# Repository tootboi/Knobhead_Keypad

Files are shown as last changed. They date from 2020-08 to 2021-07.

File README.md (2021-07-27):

# Knobhead Keypad
### Multi-functional custom Keypad

This project uses a Pro Micro with an ATmega32U4 on board. It allows the user to configure and use the rotary encoder, 9 mechanical switches and 3 rgb LEDs in many different ways, such as:
- Media keys (e.g. volume control, play/pause, ...)
- Macro keys (e.g. ctrl + Z, ctrl + shift + esc, ...)
- Mouse control (e.g. moving the cursor, middle click, ...)
- Keypad layer control
- Change LED colour and function

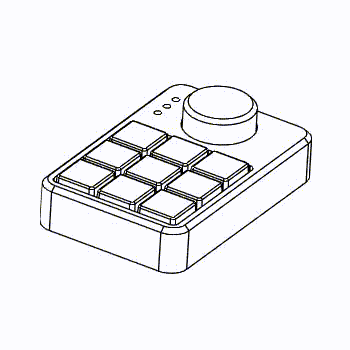
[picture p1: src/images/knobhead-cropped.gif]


## Components
- 1x Pro Micro
- 1x EC11 rotary encoder
- 9x mechanical switches
- 9x Kailh hotswap sockets
- 9x 1N4148 diodes
- 1x 28mm diameter aluminium knob OR a 3D printed knob
- 1x 3D printed case

## PCB
Autodesk Eagle files needed to view the pcb design is in Knobhead_Keypad/src/pcb/ directory.

### Schematic
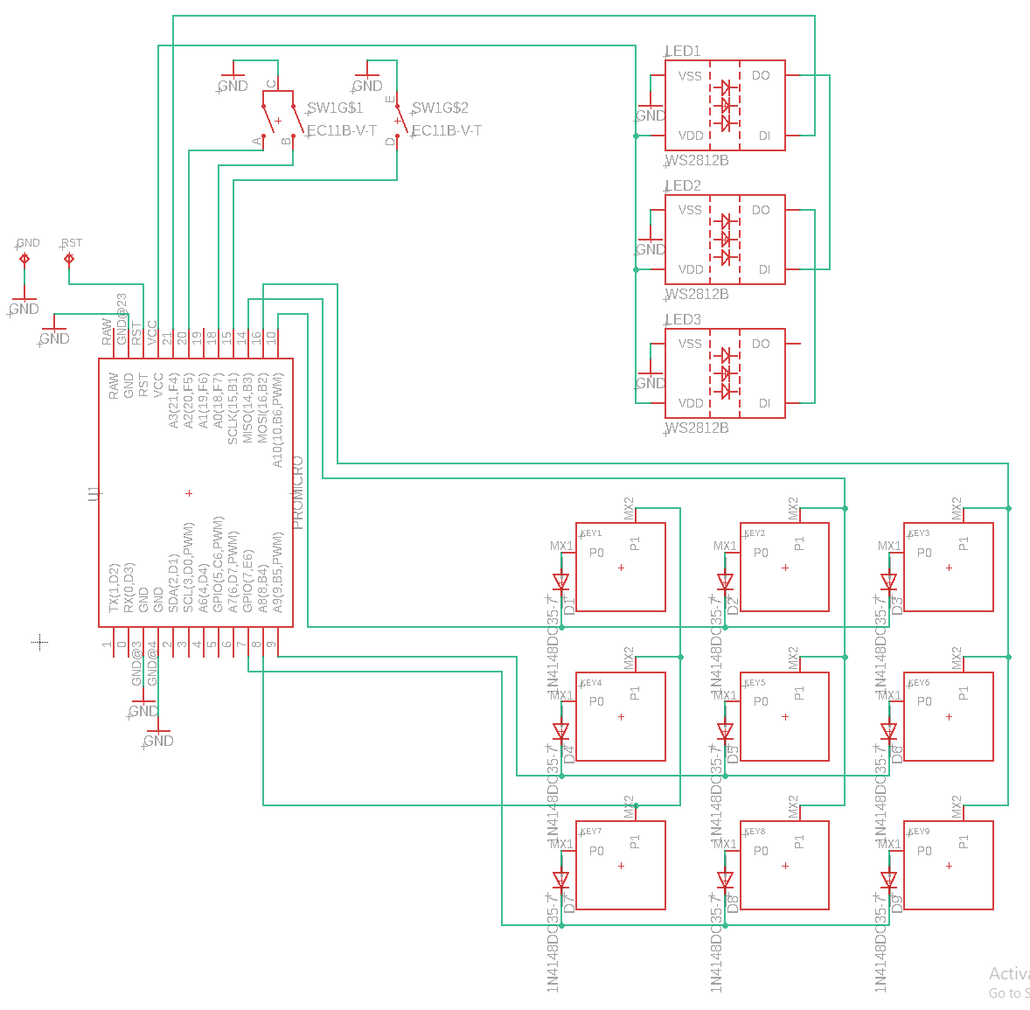
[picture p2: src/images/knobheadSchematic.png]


### Snapshot of pcb
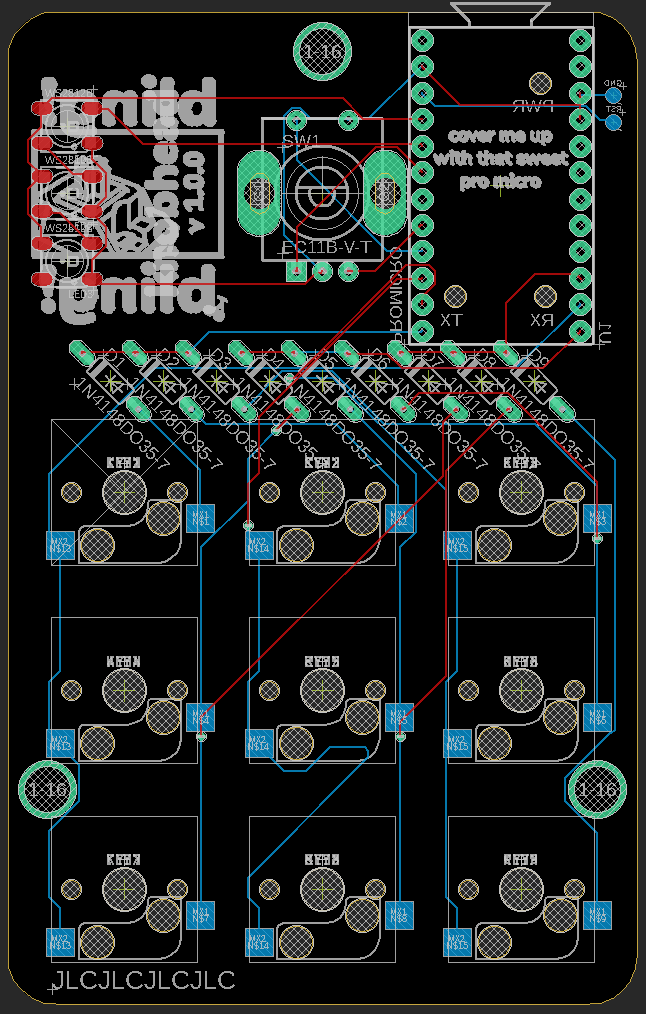
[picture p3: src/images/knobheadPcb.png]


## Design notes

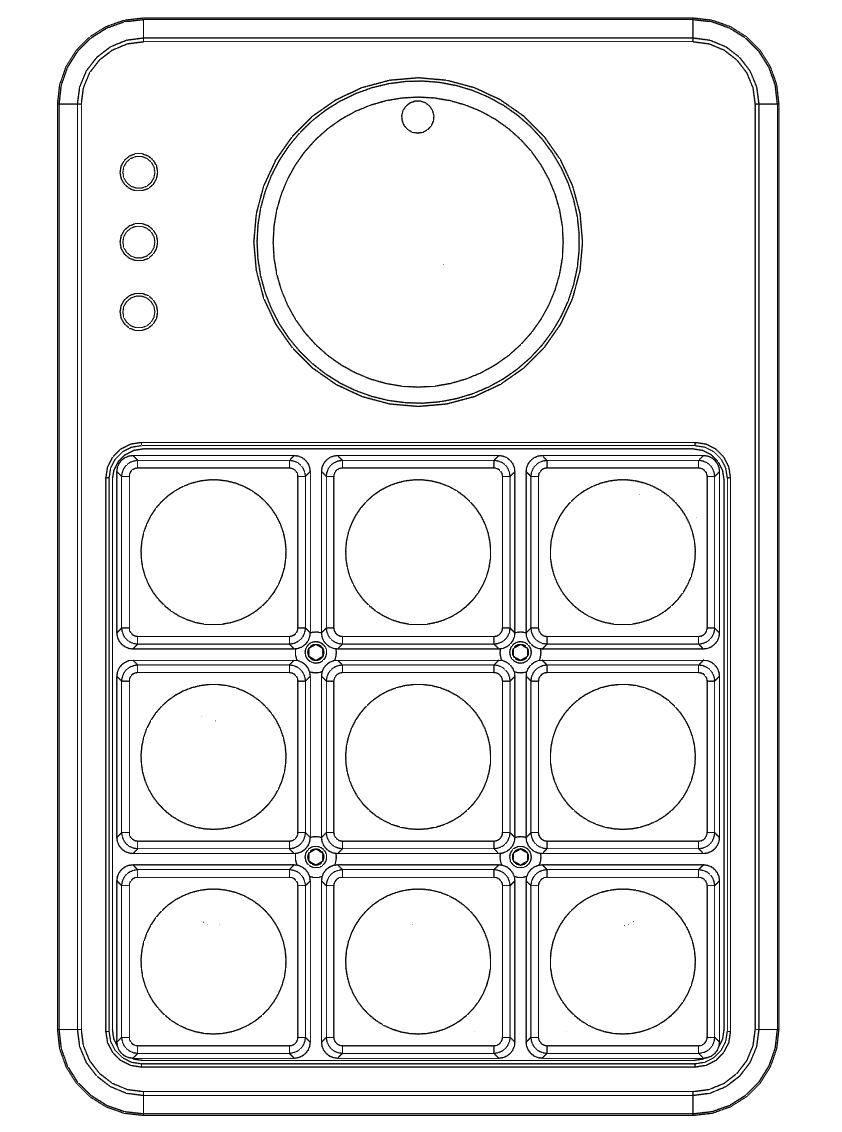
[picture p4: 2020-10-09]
src/images/front.png

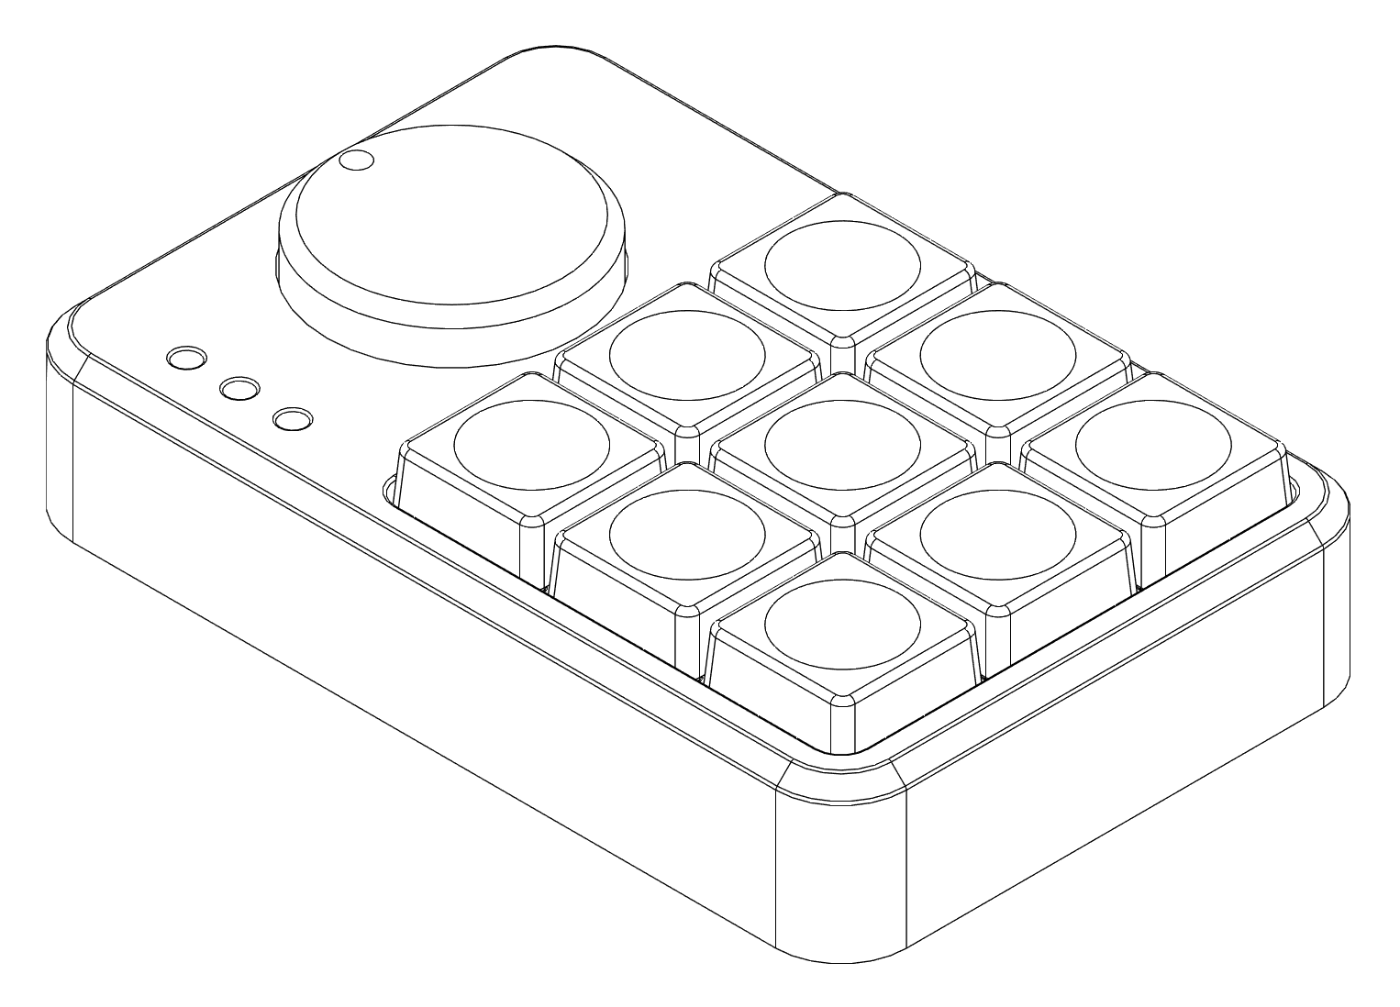
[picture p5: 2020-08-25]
src/images/isometricView.png

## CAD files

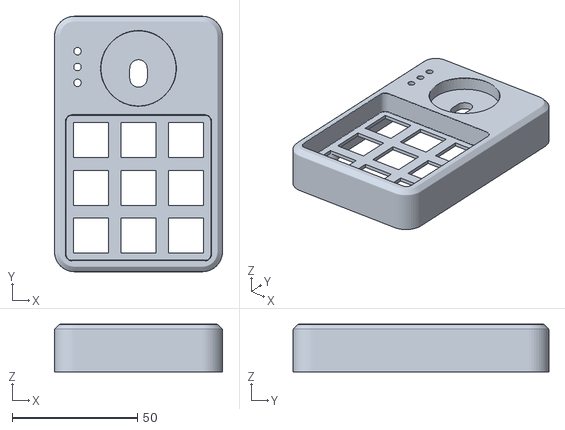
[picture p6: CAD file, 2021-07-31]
src/stl/knobheadCaseOpaque.stl
67.2 x 102.1 x 19.0

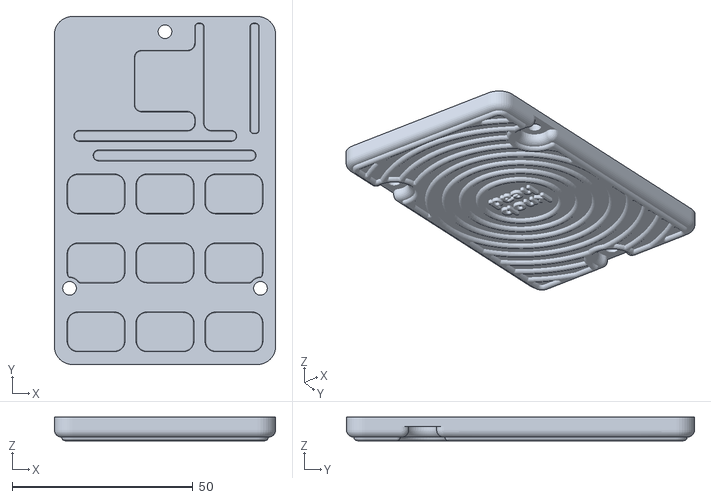
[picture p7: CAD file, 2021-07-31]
src/stl/knobheadBackplate.stl
61.2 x 96.1 x 6.50

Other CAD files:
src/stl/knobheadCaseTranslucent.stl

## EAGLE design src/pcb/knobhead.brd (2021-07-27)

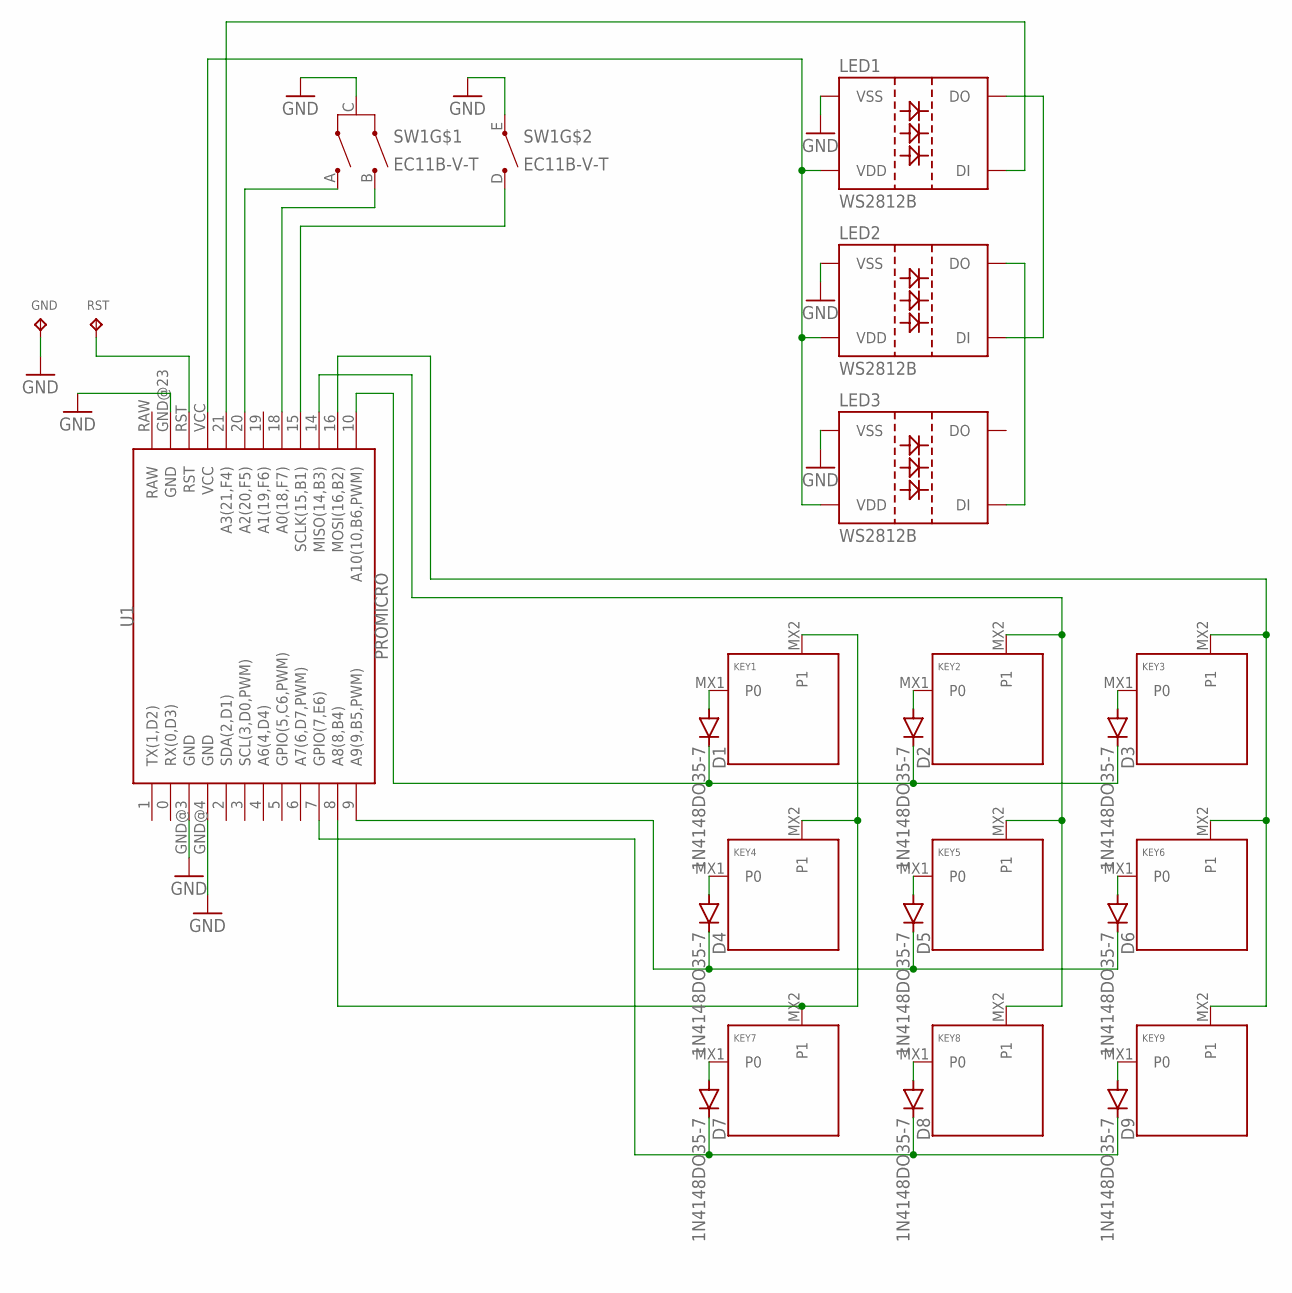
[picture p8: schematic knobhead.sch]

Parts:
D1, D2, D3, D4, D5, D6, D7, D8, D9: 1N4148DO35-7; DO35-7
GND: TPB1,27; B1,27
KEY1, KEY2, KEY3, KEY4, KEY5, KEY6, KEY7, KEY8, KEY9: KEYSWITCH-PLAIN-MXHSPCB-1U; MXHSPCB-1U
LED1, LED2, LED3: WS2812B
RST: TPB1,27; B1,27
SW1: EC11B-V-T; EC11B-V
U1: PROMICRO

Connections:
GND: GND.TP, LED1.3 (VSS), LED2.3 (VSS), LED3.3 (VSS), SW1.C, SW1.E, U1.GND@3 (GND), U1.GND@4 (GND), U1.GND@23 (GND)
unnamed: D1.A, KEY1.MX1 (P0)
unnamed: D2.A, KEY2.MX1 (P0)
unnamed: D3.A, KEY3.MX1 (P0)
unnamed: D4.A, KEY4.MX1 (P0)
unnamed: D5.A, KEY5.MX1 (P0)
unnamed: D6.A, KEY6.MX1 (P0)
unnamed: D7.A, KEY7.MX1 (P0)
unnamed: D8.A, KEY8.MX1 (P0)
unnamed: D9.A, KEY9.MX1 (P0)
unnamed: D1.C, D2.C, D3.C, U1.10 (A10(10,B6,PWM))
unnamed: D4.C, D5.C, D6.C, U1.9 (A9(9,B5,PWM))
unnamed: D7.C, D8.C, D9.C, U1.7 (GPIO(7,E6))
unnamed: KEY1.MX2 (P1), KEY4.MX2 (P1), KEY7.MX2 (P1), U1.8 (A8(8,B4))
unnamed: KEY2.MX2 (P1), KEY5.MX2 (P1), KEY8.MX2 (P1), U1.14 (MISO(14,B3))
unnamed: KEY3.MX2 (P1), KEY6.MX2 (P1), KEY9.MX2 (P1), U1.16 (MOSI(16,B2))
unnamed: LED1.1 (VDD), LED2.1 (VDD), LED3.1 (VDD), U1.VCC
unnamed: LED1.4 (DI), U1.21 (A3(21,F4))
unnamed: LED1.2 (DO), LED2.4 (DI)
unnamed: LED2.2 (DO), LED3.4 (DI)
unnamed: SW1.A, U1.20 (A2(20,F5))
unnamed: SW1.B, U1.18 (A0(18,F7))
unnamed: SW1.D, U1.15 (SCLK(15,B1))
unnamed: RST.TP, U1.RST

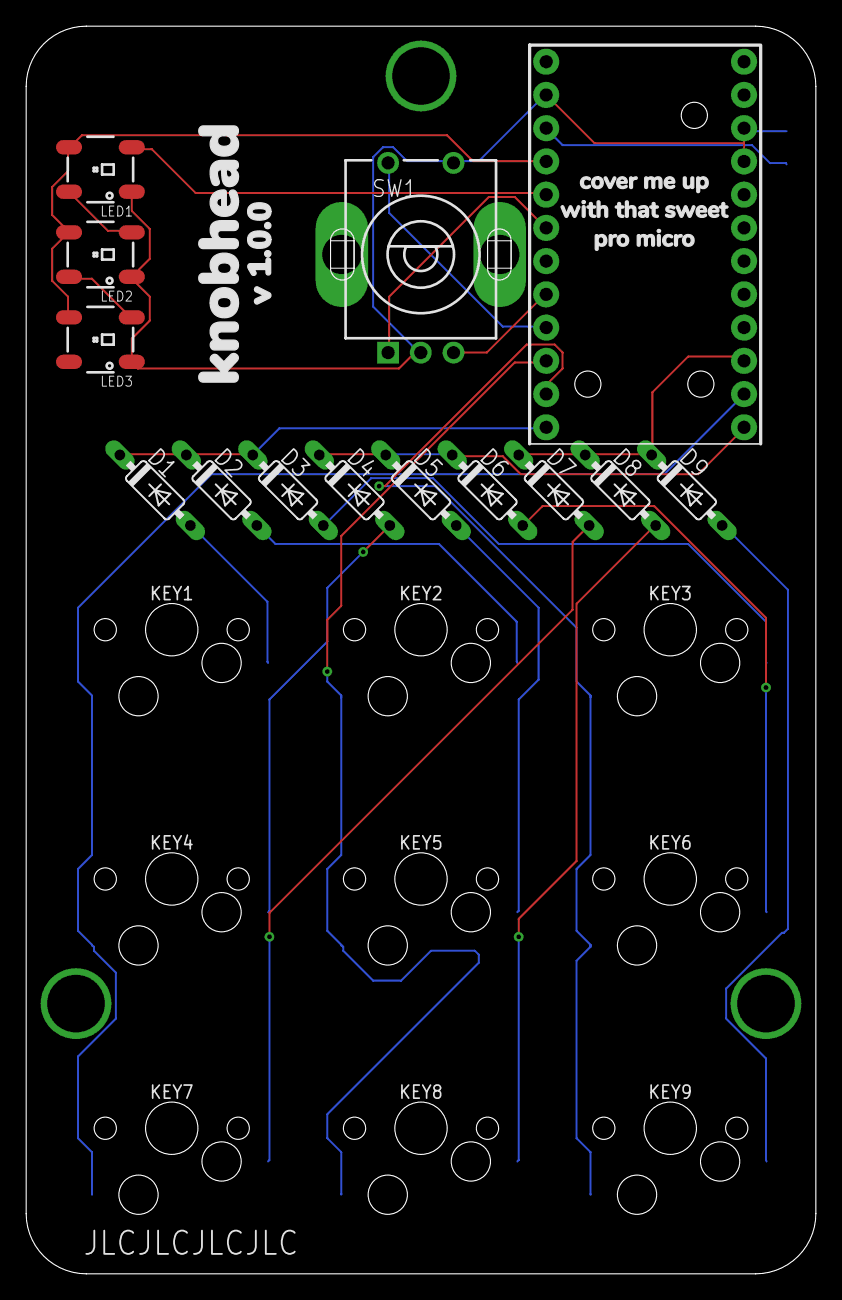
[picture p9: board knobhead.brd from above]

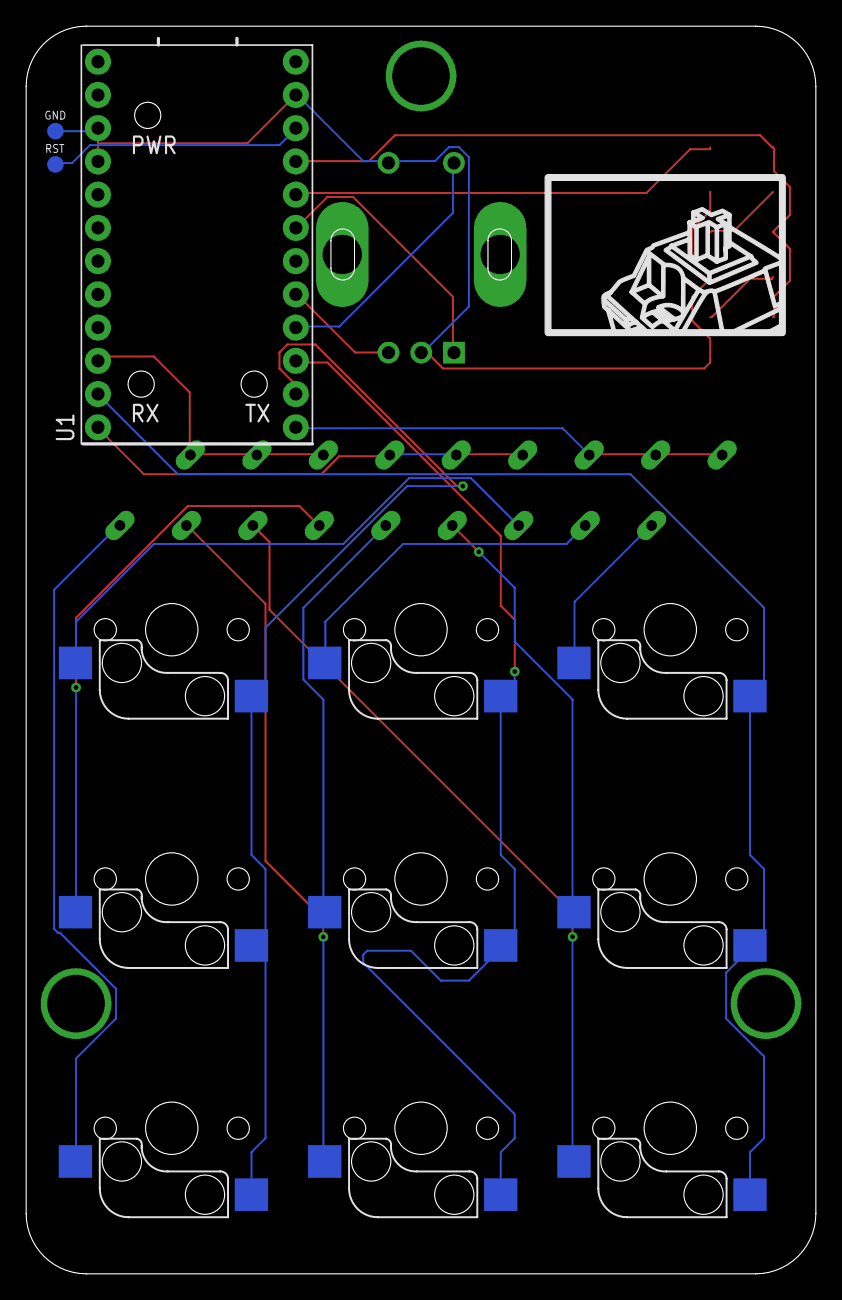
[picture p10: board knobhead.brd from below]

Board: 2 copper layers, 60.4 x 95.3 mm, 25 parts (12 on the bottom side), 24 nets.

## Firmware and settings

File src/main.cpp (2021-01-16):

#include <Arduino.h>
#include <HID-Project.h>
#include <Adafruit_NeoPixel.h>

//variables for LED timeout
const unsigned long timeout = 60000;   //timeout in millisecond. change this value to adjust timeout
unsigned long idleTime;
bool idleStart = false;
bool idle = false;
bool rainbow = false;
bool timeoutEnabled = true;

//variables for NeoPixel
#define ledStripPin A3
#define ledCount 3

Adafruit_NeoPixel strip(ledCount, ledStripPin, NEO_GRB + NEO_KHZ800);

//variables for keypad matrix
const int rowNum = 3;
const int colNum = 3;

byte rowPins[rowNum] = {10, 9, 7};
byte colPins[colNum] = {8, 14, 16};

int getKey();

//    btn matrix layout:
//    |----------------|
//    |[1]    [2]   [3]|
//    |[4]    [5]   [6]|
//    |[7]    [8]   [9]|
//    |----------------|

//variable for layers
int layer = 0;
bool subLayer = false;

void layerChange(byte sign);
void checkBit(byte layer, byte bit, byte led, uint32_t rgb);

//variables for rotary encoder
#define outputA A2
#define outputB A0
const int pulseDebounce = 0;
unsigned long lastPulse = 0;

uint8_t tableDecode();

#define encoderBtn 15

uint8_t getClick();

void setup() {
  Serial.begin(9600);

  //setup for NeoPixel
  strip.begin();
  strip.show();

  //setup for keypad matrix
  for(byte c=0; c<colNum; c++) {
    pinMode(colPins[c], INPUT_PULLUP);
  }

  //setup for rotarty encoder
  pinMode(outputA, INPUT_PULLUP);
  pinMode(outputB, INPUT_PULLUP);
  pinMode(encoderBtn, INPUT_PULLUP);

  Consumer.begin(); //For writing media keys.
  Keyboard.begin(); //For writing normal keys.
  BootKeyboard.begin(); //For keyboard leds.
  Mouse.begin();
}

void loop() {
  //for timeout
  bool noInput = true;

  //code for layer leds
  if(!idle) strip.setBrightness(12);
  switch(layer) {
    //layer 0
    case 0:
      if(subLayer) {
        //sublayer
        strip.clear();
        uint32_t color0 = strip.Color(255, 255, 0);
        uint32_t color1 = strip.Color(0, 0, 255);
        uint32_t color2 = strip.Color(0, 0, 255);
        checkBit(layer, 1, 1, color1);
        checkBit(layer, 0, 2, color2);
        //code for led indicate
        if(BootKeyboard.getLeds() & LED_CAPS_LOCK) {  //for changing what led0 indicates
          strip.setPixelColor(0, color0); //for changing led0 color
        }
      } else {
        //main
        strip.clear();
        uint32_t color0 = strip.Color(255, 255, 0);
        uint32_t color1 = strip.Color(0, 255, 0);
        uint32_t color2 = strip.Color(0, 255, 0);
        checkBit(layer, 1, 1, color1);
        checkBit(layer, 0, 2, color2);
        //code for led indicate
        if(BootKeyboard.getLeds() & LED_CAPS_LOCK) {  //for changing what led0 indicates
          strip.setPixelColor(0, color0); //for changing led0 color
        }
      }
      break;
    //layer 1
    case 1:
      if(subLayer){
        strip.clear();
        uint32_t color0 = strip.Color(255, 255, 0);
        uint32_t color1 = strip.Color(0, 0, 255);
        uint32_t color2 = strip.Color(0, 0, 255);
        checkBit(layer, 1, 1, color1);
        checkBit(layer, 0, 2, color2);
        //code for led indicate
        if(BootKeyboard.getLeds() & LED_CAPS_LOCK) {  //for changing what led0 indicates
          strip.setPixelColor(0, color0); //for changing led0 color
        }
      } else {
        strip.clear();
        uint32_t color0 = strip.Color(255, 255, 0);
        uint32_t color1 = strip.Color(0, 255, 0);
        uint32_t color2 = strip.Color(0, 255, 0);
        checkBit(layer, 1, 1, color1);
        checkBit(layer, 0, 2, color2);
        //code for led indicate
        if(BootKeyboard.getLeds() & LED_CAPS_LOCK) {  //for changing what led0 indicates
          strip.setPixelColor(0, color0); //for changing led0 color
        }
      }
      break;
    //layer 2
    case 2:
      if(subLayer){
        strip.clear();
        uint32_t color0 = strip.Color(0, 113, 128);
        uint32_t color1 = strip.Color(0, 0, 255);
        uint32_t color2 = strip.Color(0, 0, 255);
        checkBit(layer, 1, 1, color1);
        checkBit(layer, 0, 2, color2);
        //code for led indicate
        if(BootKeyboard.getLeds() & LED_NUM_LOCK) {  //for changing what led0 indicates
          strip.setPixelColor(0, color0); //for changing led0 color
        }
      } else {
        strip.clear();
        uint32_t color0 = strip.Color(255, 255, 0);
        uint32_t color1 = strip.Color(0, 255, 0);
        uint32_t color2 = strip.Color(0, 255, 0);
        checkBit(layer, 1, 1, color1);
        checkBit(layer, 0, 2, color2);
        //code for led indicate
        if(BootKeyboard.getLeds() & LED_CAPS_LOCK) {  //for changing what led0 indicates
          strip.setPixelColor(0, color0); //for changing led0 color
        }
      }
      break;
    //layer 3
    case 3:
      if(subLayer){
        strip.clear();
        uint32_t color0 = strip.Color(255, 255, 0);
        uint32_t color1 = strip.Color(0, 0, 255);
        uint32_t color2 = strip.Color(0, 0, 255);
        checkBit(layer, 1, 1, color1);
        checkBit(layer, 0, 2, color2);
        //code for led indicate
        if(BootKeyboard.getLeds() & LED_CAPS_LOCK) {  //for changing what led0 indicates
          strip.setPixelColor(0, color0); //for changing led0 color
        }
      } else {
        strip.clear();
        uint32_t color0 = strip.Color(255, 255, 0);
        uint32_t color1 = strip.Color(0, 255, 0);
        uint32_t color2 = strip.Color(0, 255, 0);
        checkBit(layer, 1, 1, color1);
        checkBit(layer, 0, 2, color2);
        //code for led indicate
        if(BootKeyboard.getLeds() & LED_CAPS_LOCK) {  //for changing what led0 indicates
          strip.setPixelColor(0, color0); //for changing led0 color
        }
      }
      break;
      
    default:
      break;
  }
  
  uint8_t clickType = getClick();
  uint8_t direction = tableDecode();
  uint8_t key = getKey();
  //for timeout
  if(key || direction || clickType) noInput = false, idleStart = true, idle = false;

  switch (layer) {
    //layer 0
    case 0:
      //code for keypad
      if(key){
        Serial.print("key: ");
        Serial.println(key);
        switch (key) {
          case 1:
            if(subLayer) {
              //sublayer
              //code    //change this line to modify functions.
            } else {
              Keyboard.print("layer 0 ");    //change this line to modify functions.
            }
            break;
          case 2:
            if(subLayer) {
              //sublayer
              //code    //change this line to modify functions.
            } else {
              Consumer.write(CONSUMER_CALCULATOR);    //change this line to modify functions.
            }
            break;
          case 3:
            if(subLayer) {
              //sublayer
              //code    //change this line to modify functions.
            } else {
              Keyboard.press(KEY_PAGE_UP);    //change this line to modify functions.
            }
            break;
          case 4:
            if(subLayer) {
              //sublayer
              //code    //change this line to modify functions.
            } else {
              Keyboard.press(KEY_LEFT_CTRL);    //change this line to modify functions.
              Keyboard.print("z");    //change this line to modify functions.
            }
            break;
          case 5:
            if(subLayer) {
              //sublayer
              //code    //change this line to modify functions.
            } else {
              Keyboard.press(KEY_LEFT_CTRL);    //change this line to modify functions.
              Keyboard.press('y');    //change this line to modify functions.
            }
            break;
          case 6:
            if(subLayer) {
              //sublayer
              //code    //change this line to modify functions.
            } else {
              Keyboard.press(KEY_PAGE_DOWN);    //change this line to modify functions.
            }
            break;
          case 7:
            if(subLayer) {
              //sublayer
              //code    //change this line to modify functions.
            } else {
              Keyboard.press(KEY_LEFT_CTRL);    //change this line to modify functions.
              Keyboard.press('x');    //change this line to modify functions.
            }
            break;
          case 8:
            if(subLayer) {
              //sublayer
              //code    //change this line to modify functions.
            } else {
              Keyboard.press(KEY_LEFT_CTRL);    //change this line to modify functions.
              Keyboard.press('c');    //change this line to modify functions.
            }
            break;
          case 9:
            if(subLayer) {
              //sublayer
              //code    //change this line to modify functions.
            } else {
              Keyboard.press(KEY_LEFT_CTRL);    //change this line to modify functions.
              Keyboard.press('v');    //change this line to modify functions.
            }
            break;

          default:
            break;
        }
        Keyboard.releaseAll();    //release all keys
      }
      
      //code for rotary encoder
      if(clickType) {
        switch(clickType) {
          case 1: //single
            if(subLayer) {
              //sublayer
              subLayer = !subLayer;
            } else {
              Consumer.write(MEDIA_VOLUME_MUTE);
            }
            break;
          case 2: //double
            if(subLayer) {
              //sublayer
              layerChange(0);
            } else {
              layerChange(0);
            }
            break;
          case 3: //long
            if(subLayer) {
              //sublayer
              layerChange(1);
            } else {
              layerChange(1);
            }
            break;

          default:
            break;
        }
        clickType = 0;
      }
      if(direction) {
        switch (direction) {
          case 1:     //clockwise
            if(subLayer) {
              Consumer.write(MEDIA_VOLUME_UP);
            } else {
              Consumer.write(MEDIA_VOLUME_UP);
            }
            break;
          case 2:     //anti-clockwise
            if(subLayer) {
              Consumer.write(MEDIA_VOLUME_DOWN);
            } else {
              Consumer.write(MEDIA_VOLUME_DOWN);
            }
            break;

          default:
            break;
        }
      }
      Keyboard.releaseAll();    //release all keys
      break;
      
    //layer 1
    case 1:
      //code for keypad
      if(key){
        Serial.print("key: ");
        Serial.println(key);
        switch (key) {
          case 1:
            if(subLayer) {
              //sublayer
              //code    //change this line to modify functions.
            } else {
              Keyboard.print("layer 1 ");    //change this line to modify functions.
            }
            break;
          case 2:
            if(subLayer) {
              //sublayer
              //code    //change this line to modify functions.
            } else {
              Keyboard.press(KEY_LEFT_SHIFT);    //change this line to modify functions.
              Keyboard.press(KEY_LEFT_ALT);    //change this line to modify functions.
              Keyboard.press(KEY_LEFT_CTRL);    //change this line to modify functions.
              Keyboard.press(KEY_F1);    //change this line to modify functions.
            }
            break;
          case 3:
            if(subLayer) {
              //sublayer
              //code    //change this line to modify functions.
            } else {
              rainbow = !rainbow;    //change this line to modify functions.
            }
            break;
          case 4:
            if(subLayer) {
              //sublayer
              //code    //change this line to modify functions.
            } else {
              //code    //change this line to modify functions.
            }
            break;
          case 5:
            if(subLayer) {
              //sublayer
              //code    //change this line to modify functions.
            } else {
              //code    //change this line to modify functions.
            }
            break;
          case 6:
            if(subLayer) {
              //sublayer
              //code    //change this line to modify functions.
            } else {
              //code    //change this line to modify functions.
            }
            break;
          case 7:
            if(subLayer) {
              //sublayer
              //code    //change this line to modify functions.
            } else {
              //code    //change this line to modify functions.
            }
            break;
          case 8:
            if(subLayer) {
              //sublayer
              //code    //change this line to modify functions.
            } else {
              //code    //change this line to modify functions.
            }
            break;
          case 9:
            if(subLayer) {
              //sublayer
              //code    //change this line to modify functions.
            } else {
              //code    //change this line to modify functions.
            }
            break;

          default:
            break;
        }
        Keyboard.releaseAll();    //release all keys
      }
      
      //code for rotary encoder
      if(clickType) {
        switch(clickType) {
          case 1: //single
            if(subLayer) {
              subLayer = !subLayer;
            } else {
              Consumer.write(MEDIA_VOLUME_MUTE);
            }
            break;
          case 2: //double
            if(subLayer) {
              layerChange(0);
            } else {
              layerChange(0);
            }
            break;
          case 3: //long
            if(subLayer) {
              layerChange(1);
            } else {
              layerChange(1);
            }
            break;

          default:
            break;
        }
        clickType = 0;
      }
      if(direction) {
        switch (direction) {
          case 1:     //clockwise
            if(subLayer) {
              Consumer.write(MEDIA_VOLUME_UP);
            } else {
              Consumer.write(MEDIA_VOLUME_UP);
            }
            break;
          case 2:     //anti-clockwise
            if(subLayer) {
              Consumer.write(MEDIA_VOLUME_DOWN);
            } else {
              Consumer.write(MEDIA_VOLUME_DOWN);
            }              
            break;

          default:
            break;
        }
      }
      Keyboard.releaseAll();  
      break;

    //layer 2
    case 2:
      //code for keypad
      if(key){
        Serial.print("key: ");
        Serial.println(key);
        switch (key) {
          case 1:
            if(subLayer) {
              //sublayer
              Keyboard.press(KEY_NUM_LOCK);    //change this line to modify functions.
            } else {
              Keyboard.press(KEYPAD_1);    //change this line to modify functions.
            }
            break;
          case 2:
            if(subLayer) {
              //sublayer
              //code    //change this line to modify functions.
            } else {
              Keyboard.press(KEYPAD_2);    //change this line to modify functions.
            }
            break;
          case 3:
            if(subLayer) {
              //sublayer
              //code    //change this line to modify functions.
            } else {
              Keyboard.press(KEYPAD_3);    //change this line to modify functions.
            }
            break;
          case 4:
            if(subLayer) {
              //sublayer
              //code    //change this line to modify functions.
            } else {
              Keyboard.press(KEYPAD_4);    //change this line to modify functions.
            }
            break;
          case 5:
            if(subLayer) {
              //sublayer
              //code    //change this line to modify functions.
            } else {
              Keyboard.press(KEYPAD_5);    //change this line to modify functions.
            }
            break;
          case 6:
            if(subLayer) {
              //sublayer
              //code    //change this line to modify functions.
            } else {
              Keyboard.press(KEYPAD_6);    //change this line to modify functions.
            }
            break;
          case 7:
            if(subLayer) {
              //sublayer
              Keyboard.press(KEYPAD_0);    //change this line to modify functions.
            } else {
              Keyboard.press(KEYPAD_7);    //change this line to modify functions.
            }
            break;
          case 8:
            if(subLayer) {
              //sublayer
              //code    //change this line to modify functions.
            } else {
              Keyboard.press(KEYPAD_8);    //change this line to modify functions.
            }
            break;
          case 9:
            if(subLayer) {
              //sublayer
              //code    //change this line to modify functions.
            } else {
              Keyboard.press(KEYPAD_9);    //change this line to modify functions.
            }
            break;

          default:
            break;
        }
        Keyboard.releaseAll();    //release all keys
      }
      
      //code for rotary encoder
      if(clickType) {
        switch(clickType) {
          case 1: //single
            if(subLayer) {
              subLayer = !subLayer;
            } else {
              subLayer = !subLayer;
            }              
            break;
          case 2: //double
            if(subLayer) {
              layerChange(0);
            } else {
              layerChange(0);
            }              
            break;
          case 3: //long
            if(subLayer) {
              layerChange(1);
            } else {
              layerChange(1);
            }              
            break;

          default:
            break;
        }
        clickType = 0;
      }
      if(direction) {
        switch (direction) {
          case 1:     //clockwise
            if(subLayer) {
              Keyboard.press(KEY_LEFT_CTRL);    //change this line to modify functions.
              Keyboard.press('+');    //change this line to modify functions.
            } else {
              Consumer.write(MEDIA_VOLUME_UP);
            }
            break;
          case 2:     //anti-clockwise
            if(subLayer) {
              Keyboard.press(KEY_LEFT_CTRL);    //change this line to modify functions.
              Keyboard.press('-');    //change this line to modify functions.
            } else {
              Consumer.write(MEDIA_VOLUME_DOWN);
            }
            break;

          default:
            break;
        }
      }
      Keyboard.releaseAll(); 
      break;

    //layer 3
    case 3:
      //code for keypad
      if(key){
        Serial.print("key: ");
        Serial.println(key);
        switch (key) {
          case 1:
            if(subLayer) {
              //sublayer
              //code    //change this line to modify functions.
            } else {
              Keyboard.print("1");    //change this line to modify functions.
            }
            break;
          case 2:
            if(subLayer) {
              //sublayer
              //code    //change this line to modify functions.
            } else {
              Keyboard.print("2");    //change this line to modify functions.
            }
            break;
          case 3:
            if(subLayer) {
              //sublayer
              //code    //change this line to modify functions.
            } else {
              Keyboard.print("3");   //change this line to modify functions.
            }
            break;
          case 4:
            if(subLayer) {
              //sublayer
              //code    //change this line to modify functions.
            } else {
              Keyboard.print("4");    //change this line to modify functions.
            }
            break;
          case 5:
            if(subLayer) {
              //sublayer
              //code    //change this line to modify functions.
            } else {
              Keyboard.print("5");    //change this line to modify functions.
            }
            break;
          case 6:
            if(subLayer) {
              //sublayer
              //code    //change this line to modify functions.
            } else {
              Keyboard.print("6");    //change this line to modify functions.
            }
            break;
          case 7:
            if(subLayer) {
              //sublayer
              //code    //change this line to modify functions.
            } else {
              Keyboard.print("7");    //change this line to modify functions.
            }
            break;
          case 8:
            if(subLayer) {
              //sublayer
              //code    //change this line to modify functions.
            } else {
              Keyboard.print("8");    //change this line to modify functions.
            }
            break;
          case 9:
            if(subLayer) {
              //sublayer
              //code    //change this line to modify functions.
            } else {
              Keyboard.print("9");    //change this line to modify functions.
            }
            break;
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

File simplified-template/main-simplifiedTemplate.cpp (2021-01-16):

#include <Arduino.h>
#include <HID-Project.h>
#include <Adafruit_NeoPixel.h>

#define ledStripPin A3
#define ledCount 3
#define outputA A2
#define outputB A0
#define encoderBtn 15

const unsigned long timeout = 60000;
unsigned long idleTime;
bool idleStart = false;
bool idle = false;
bool rainbow = false;
bool timeoutEnabled = false;
const int rowNum = 3;
const int colNum = 3;
byte rowPins[rowNum] = {10, 9, 7};
byte colPins[colNum] = {8, 14, 16};
int layer = 0;
bool subLayer = false;
const int pulseDebounce = 0;
unsigned long lastPulse = 0;

Adafruit_NeoPixel strip(ledCount, ledStripPin, NEO_GRB + NEO_KHZ800);

int getKey();
void layerChange(byte sign);
void checkBit(byte layer, byte bit, byte led, uint32_t rgb);
uint8_t tableDecode();
uint8_t getClick();

void setup() {
  Serial.begin(9600);
  strip.begin();
  strip.show();
  for(byte c=0; c<colNum; c++) {
    pinMode(colPins[c], INPUT_PULLUP);
  }
  pinMode(outputA, INPUT_PULLUP);
  pinMode(outputB, INPUT_PULLUP);
  pinMode(encoderBtn, INPUT_PULLUP);
  Consumer.begin();
  Keyboard.begin();
  BootKeyboard.begin();
  Mouse.begin();
}

void loop() {
  bool noInput = true;
  if(!idle) strip.setBrightness(12);

  switch(layer) {
    //layer 0
    case 0:
      if(subLayer) {
        //sublayer 0
        strip.clear();
      } else {
        //mainlayer 0
        strip.clear();
      }
      break;
    //layer 1
    case 1:
      if(subLayer){
        //sublayer 1
        strip.clear();
      } else {
        //mainlayer 1
        strip.clear();
      }
      break;
    //layer 2
    case 2:
      if(subLayer){
        //sublayer 2
        strip.clear();
      } else {
        //mainlayer 2
        strip.clear();
      }
      break;
    //layer 3
    case 3:
      if(subLayer){
        //sublayer 3
        strip.clear();
      } else {
        //mainlayer 3
        strip.clear();
      }
      break;
      
    default:
      break;
  }
  
  uint8_t clickType = getClick();
  uint8_t direction = tableDecode();
  uint8_t key = getKey();
  if(key || direction || clickType) noInput = false, idleStart = true, idle = false;

  switch (layer) {
    //layer 0
    case 0:
      if(key){
        switch (key) {
          case 1:
            if(subLayer) {
              //sublayer 0 key 1
            } else {
              //mainlayer 0 key 1
            }
            break;
          case 2:
            if(subLayer) {
              //sublayer 0 key 2
            } else {
              //mainlayer 0 key 2
            }
            break;
          case 3:
            if(subLayer) {
              //sublayer 0 key 3
            } else {
              //mainlayer 0 key 3
            }
            break;
          case 4:
            if(subLayer) {
              //sublayer 0 key 4
            } else {
              //mainlayer 0 key 4
            }
            break;
          case 5:
            if(subLayer) {
              //sublayer 0 key 5
            } else {
              //mainlayer 0 key 5
            }
            break;
          case 6:
            if(subLayer) {
              //sublayer 0 key 6
            } else {
              //mainlayer 0 key 6
            }
            break;
          case 7:
            if(subLayer) {
              //sublayer 0 key 7
            } else {
              //mainlayer 0 key 7
            }
            break;
          case 8:
            if(subLayer) {
              //sublayer 0 key 8
            } else {
              //mainlayer 0 key 8
            }
            break;
          case 9:
            if(subLayer) {
              //sublayer 0 key 9
            } else {
              //mainlayer 0 key 9
            }
            break;

          default:
            break;
        }
        Keyboard.releaseAll();
      }
      
      if(clickType) {
        switch(clickType) {
          case 1: //single
            if(subLayer) {
              //sublayer 0 single
            } else {
              //mainlayer 0 single
            }
            break;
          case 2: //double
            if(subLayer) {
              //sublayer 0 double
            } else {
              //mainlayer 0 double
            }
            break;
          case 3: //long
            if(subLayer) {
              //sublayer 0 long
            } else {
              //mainlayer 0 long
            }
            break;

          default:
            break;
        }
        clickType = 0;
      }
      if(direction) {
        switch (direction) {
          case 1:     //clockwise
            if(subLayer) {
              //sublayer 0 cw
            } else {
              //mainlayer 0 cw
            }
            break;
          case 2:     //anti-clockwise
            if(subLayer) {
              //sublayer 0 ccw
            } else {
              //mainlayer 0 ccw
            }
            break;

          default:
            break;
        }
      }
      Keyboard.releaseAll();
      break;
      
    //layer 1
    case 1:
      if(key){
        switch (key) {
          case 1:
            if(subLayer) {
              //sublayer 1 key 1
            } else {
              //mainlayer 1 key 1
            }
            break;
          case 2:
            if(subLayer) {
              //sublayer 1 key 2
            } else {
              //mainlayer 1 key 2
            }
            break;
          case 3:
            if(subLayer) {
              //sublayer 1 key 3
            } else {
              //mainlayer 1 key 3
            }
            break;
          case 4:
            if(subLayer) {
              //sublayer 1 key 4
            } else {
              //mainlayer 1 key 4
            }
            break;
          case 5:
            if(subLayer) {
              //sublayer 1 key 5
            } else {
              //mainlayer 1 key 5
            }
            break;
          case 6:
            if(subLayer) {
              //sublayer 1 key 6
            } else {
              //mainlayer 1 key 6
            }
            break;
          case 7:
            if(subLayer) {
              //sublayer 1 key 7
            } else {
              //mainlayer 1 key 7
            }
            break;
          case 8:
            if(subLayer) {
              //sublayer 1 key 8
            } else {
              //mainlayer 1 key 8
            }
            break;
          case 9:
            if(subLayer) {
              //sublayer 1 key 9
            } else {
              //mainlayer 1 key 9
            }
            break;
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

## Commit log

2020-08-25 capsLock LED implemented
2020-08-26 double clicking with encoder implemented
2020-08-28 fixed bug where encoder button presses will somtimes have ghost presses
    [main.cpp]
2020-08-30 implemented layers for the rotary encoder
2020-09-11 implemented functionality to hold and rotate rotary encoder
2020-09-26 now uses an led strip instead of individual leds
2020-09-28 reduced pulseDebounce for more responsive rotary encoder. And minor code refactoring
2020-09-28 encoder button now has layers
2020-10-23 edited some variables so it works with pcb and now uses row scan matrix
2021-01-09 fixed noisy rotary encoder output
    [main.cpp]
2021-01-11 debugging for rotary encoder
2021-01-12 implemented timeout for LED's
2021-07-27 uploaded pcb related material
    [knobhead.brd, knobhead.sch]
2021-07-31 added stl files
    [knobheadBackplate.stl, knobheadCaseOpaque.stl, knobheadCaseTranslucent.stl]
